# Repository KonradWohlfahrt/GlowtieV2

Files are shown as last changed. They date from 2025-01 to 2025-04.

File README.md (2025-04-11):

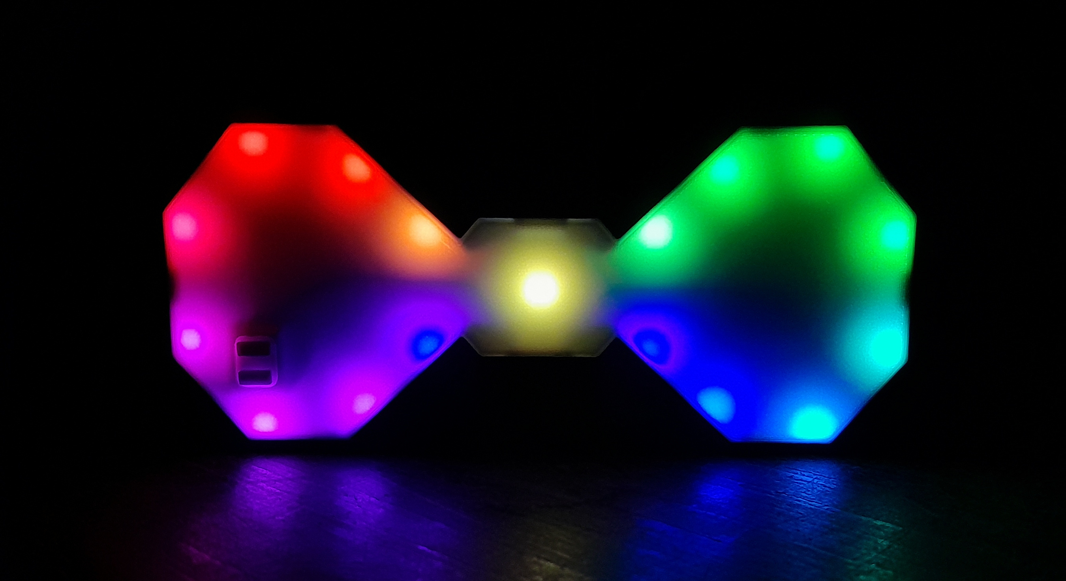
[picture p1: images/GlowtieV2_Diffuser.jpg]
Diffuser


# Glowtie V2
**Version 2 of my Glowtie adaptation: More glow for less (bow)tie!**
In this repo you will find the new project files for version 2 of the Glowtie!
It was originally designed by [Stephen Hawes](https://github.com/sphawes/glowtie).
Version 1 has served me well, but I still wanted to impove on the features and its look!
The old ESP8266 chip and Micro USB socket were exchanged with USB-C and the ESP32 C3.
Apart from two buttons and an I2S microphone, four more WS2812b leds were added to a slightly smaller pcb.
Finally, this project was made possible by [PCBWay](https://www.pcbway.com/)!
The awesome looking pcb for this project was fabricated by them.
Like last time I was satisfied with the quality and the black finish.
Creating circuit boards can be a tough task, but with such services it's made fast and simple!
If you have a project that involves pcb prototype, PCBWay offers services, such as pcb production, assembly as well as 3D printing and CNC machining for a small price!
Check out my full [guide](https://www.instructables.com/Glowtie-V2-a-Glowing-Bowtie/) at Instructables if you want to build one yourself too.

***
# Materials:
| Component | Amount | Silkscreen label |
|:---|:---:|---:|
| custom pcb | 1 | - |
| 3D printed case | 1 | - |
| 500 mAh LiPo battery (max size: 25mm x 35mm x 7mm) | 1 | - |
| M3x6 screw with nut | 2 | - |
| 100uF 1206 | 1 | C5 |
| 10uF 0805 | 3 | C2, C7, C8 |
| 1uF 0805 | 2 | C4, C6 |
| 100nF 0805 | 20 | C1, C3, C9-C27 |
| LED red 0805 | 1 | LED1 |
| LED green 0805 | 1 | LED2 |
| WS2812b 5050 | 17 | LED3-LED19 |
| 100r 0805 | 1 | R4 |
| 330r 0805 | 1 | R10 |
| 1k 0805 | 3 | R2, R3, R5 |
| 3k 0805 (charge programming resistor) | 1 | R1 |
| 10k 0805 | 5 | R6-R9, R12 |
| 33k 0805 | 1 | R11 |
| TP4056 | 1 | U4 |
| DW01A | 1 | U5 |
| FS8205A | 1 | Q1 |
| MCP1826S-3302 | 1 | U3 |
| ESP32-C3-WROOM-02 | 1 | U1 |
| SMD button 3 * 6 * 2.5 | 2 | SW2, SW3 |
| USB Type-C 4 pin | 1 | USB1 |
| SK12D07VG6 | 1 | SW1 |
| INMP441 I2S mic module | 1 | U2 |

***
# Schematic:
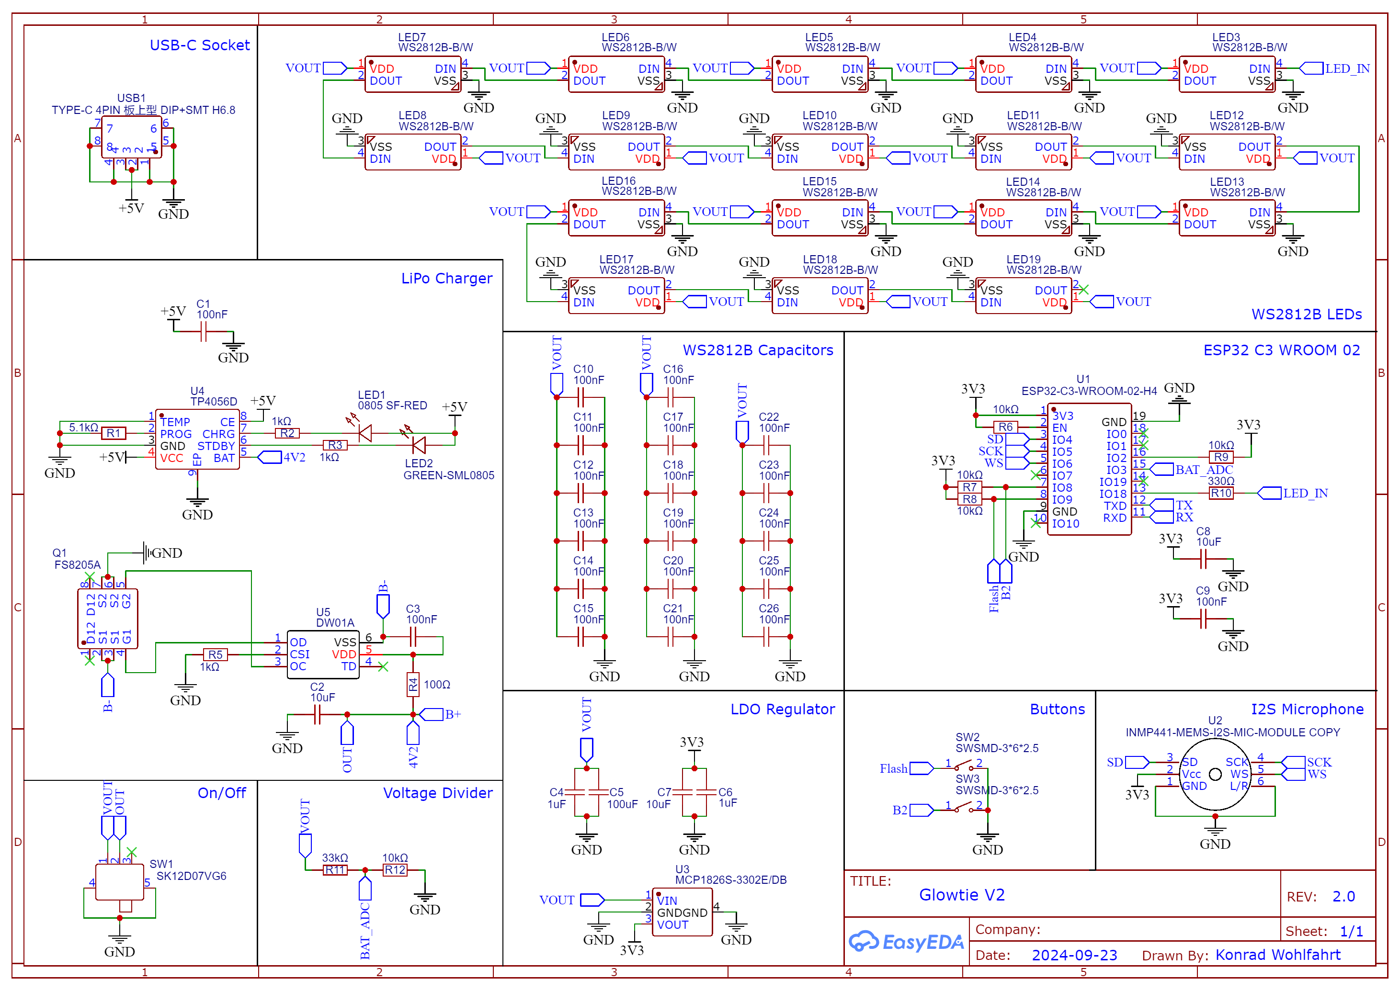
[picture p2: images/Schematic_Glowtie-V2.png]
Schematic

_Schematic for Version 2_
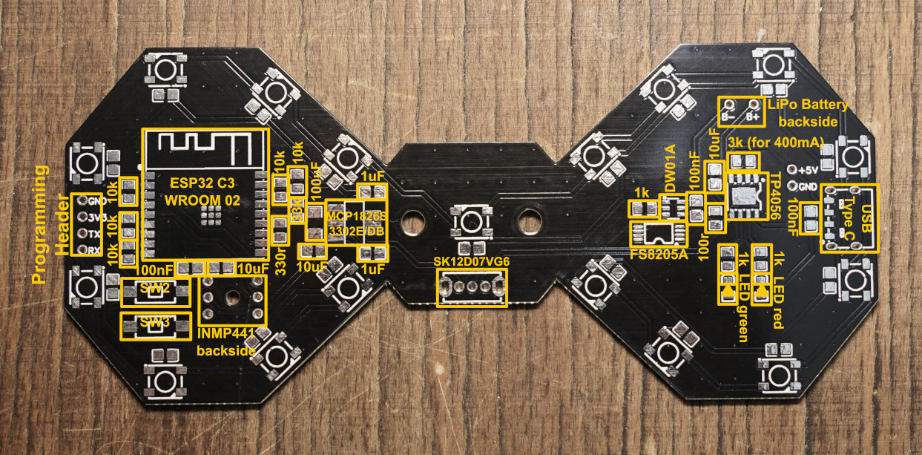
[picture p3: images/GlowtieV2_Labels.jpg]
SolderingLables

_Lables for soldering components_

**Note:**
During the development I have discovered an issue regarding the WiFi-Version:
I connected ADC Channel 2 (GPIO5) with the I2S microphone. During WiFi operation it won't be available!
Thus, you cannot use the music reactive effects while keeping WiFi enabled. 

***
# Programming
Programmed with the Arduino IDE and ESP32 board manager. 
Install the following libraries:

WiFi Version
- [WS2812FX](https://github.com/kitesurfer1404/WS2812FX)
- [ESPAsyncWebServer](https://github.com/me-no-dev/ESPAsyncWebServer)

BLE/Mic Version
- [WS2812FX](https://github.com/kitesurfer1404/WS2812FX)
- [ArduinoFFT](https://github.com/kosme/arduinoFFT)

**Uploading:**
Board: `ESP32C3 Dev Module`
Settings: default
Connections for FTDI programmer (3.3V logic level):
- Glowtie -> FTDI
- TX -> RX
- RX -> TX
- VCC -> VCC
- GND -> GND
Press and hold the upper button (Flash) when powering up the programmer until the sketch started uploading.
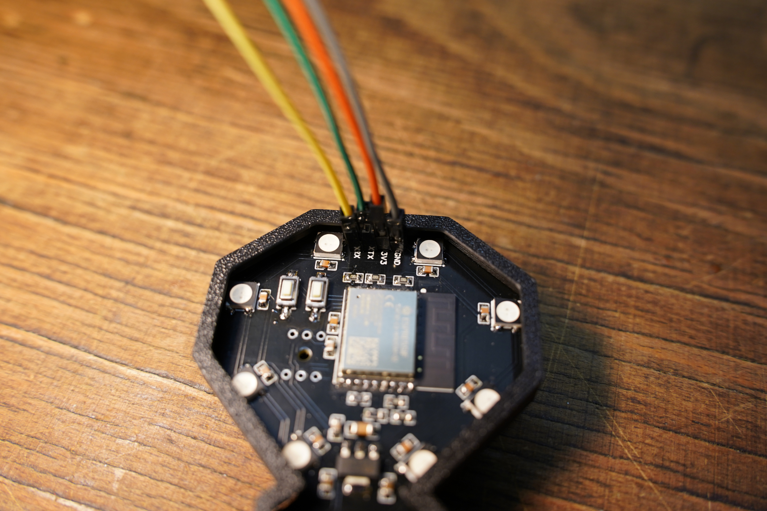
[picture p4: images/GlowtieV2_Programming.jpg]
Programming


***
# 3D Printing
Depending on your application you want to print `Glowtie` or `Glowtie Slot`, both upside down with support enabled. The `Bumper` is optional but will make it look better and offers protection. The `Diffuser` can only be placed on the bumper and will hide the pcb as well as diffuse the leds. This makes the Glowtie look more elegant! Keep in mind that if you want to access the buttons, print `Diffuser Cutout` and the corresponding button raiser.

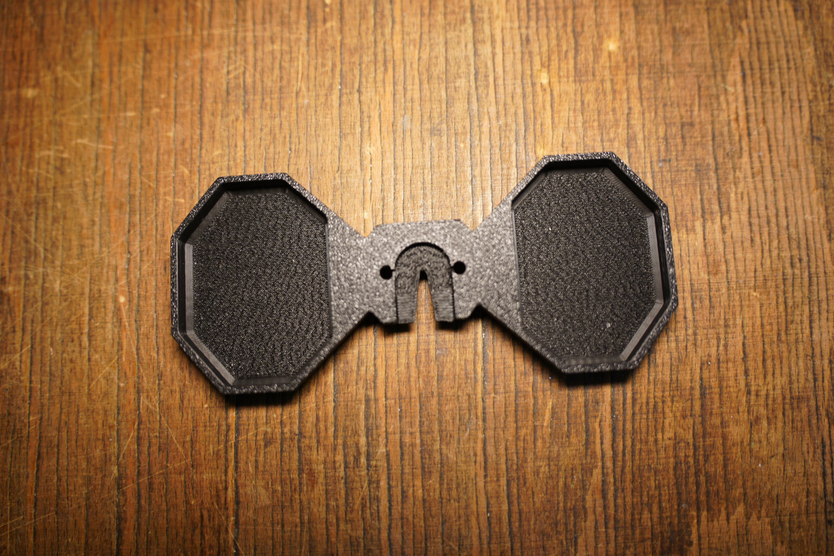
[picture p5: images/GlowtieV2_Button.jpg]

_case for button_
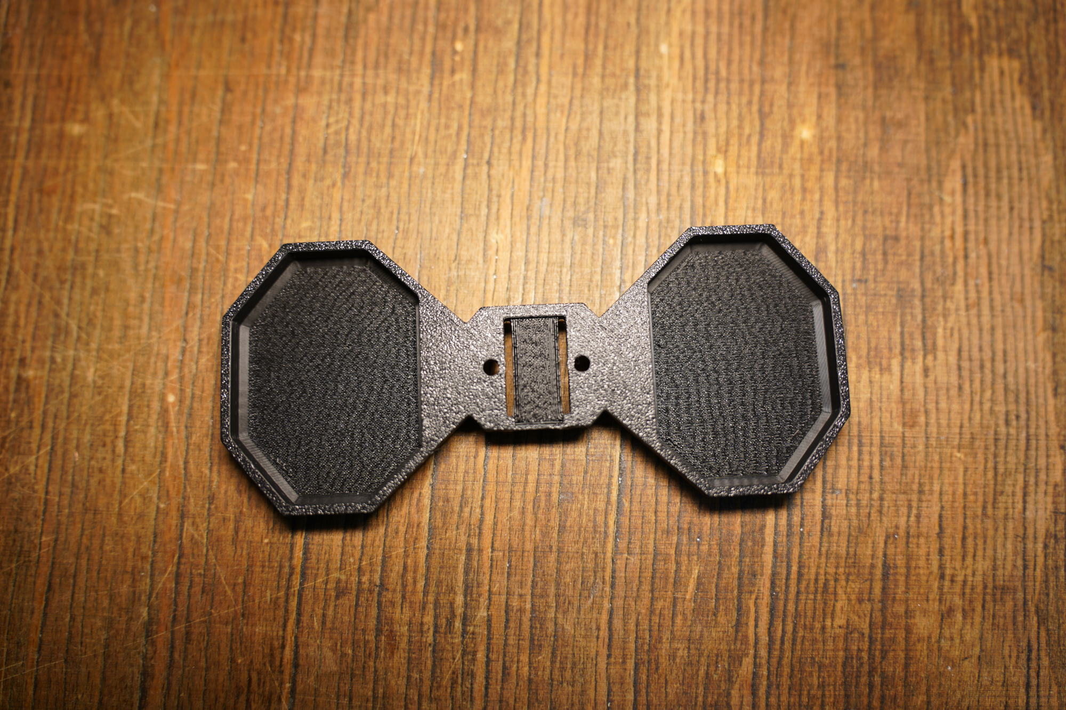
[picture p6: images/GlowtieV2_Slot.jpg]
RibbonCase

_case for ribbon_

***
# BLE Application
With Bluetooth Low Energy you need a dedicated application to change the characteristics.
I soon realized that learning a new framework takes a lot of time, so I opted for [MIT App Inventor](https://appinventor.mit.edu/).
Building your own app with this tool is easy and fast with the cost of less freedom when it comes to design.
I will come back and create a proper app with a framework like React Native or .Net Maui.
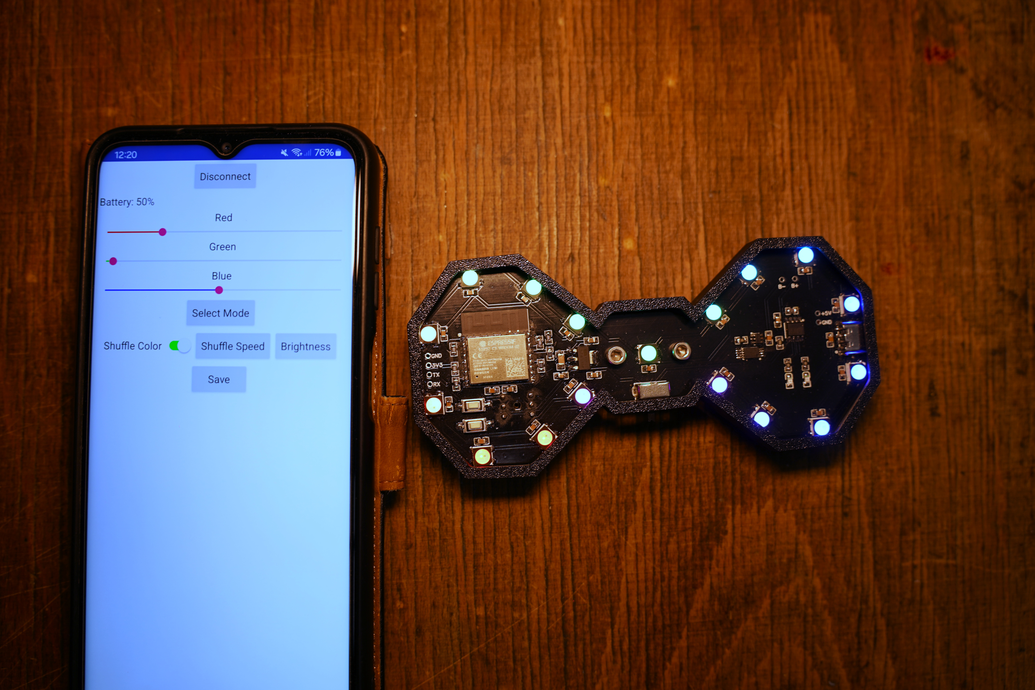
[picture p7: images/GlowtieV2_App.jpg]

_MIT App Inventor Application_

***
# Functions
The following buttons are used: upper button (Flash or B1) and lower button (B2).
Button functions:
- short press B1: show battery status
- short press B2: shuffle mode
- long press B1: save mode and color to eeprom
- long press B2: music mode
- double press B1: start BLE advertising (ble version) / swap to next effect (mic version)

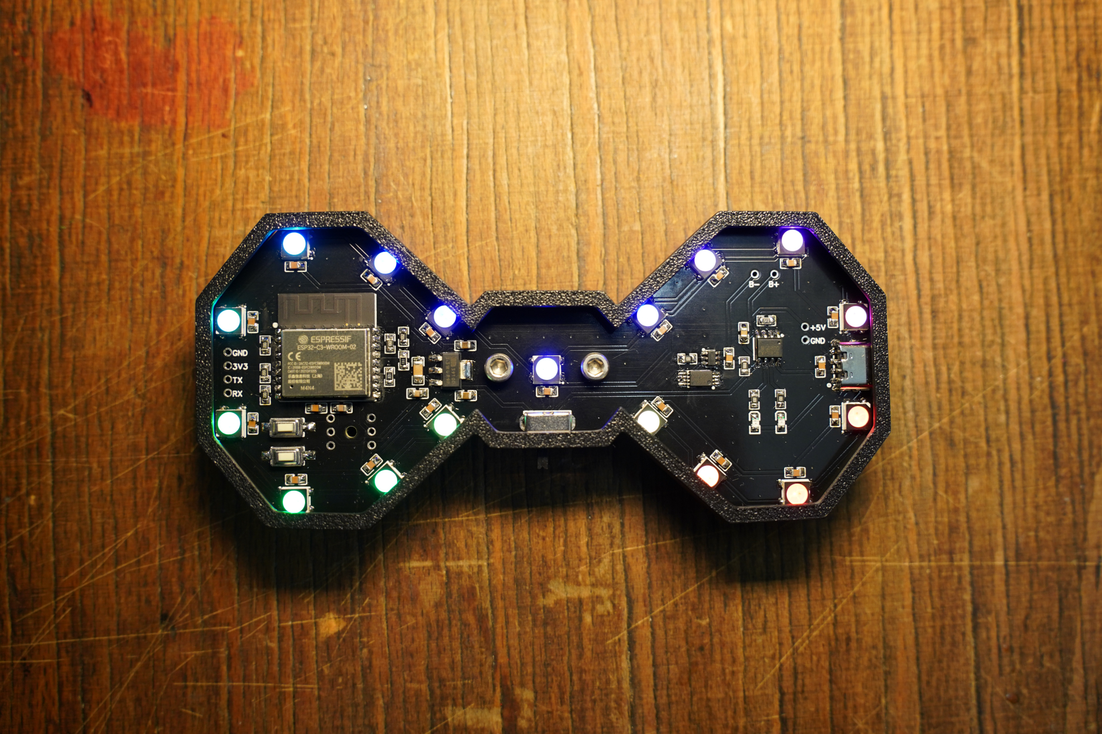
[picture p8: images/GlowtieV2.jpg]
Glowtie

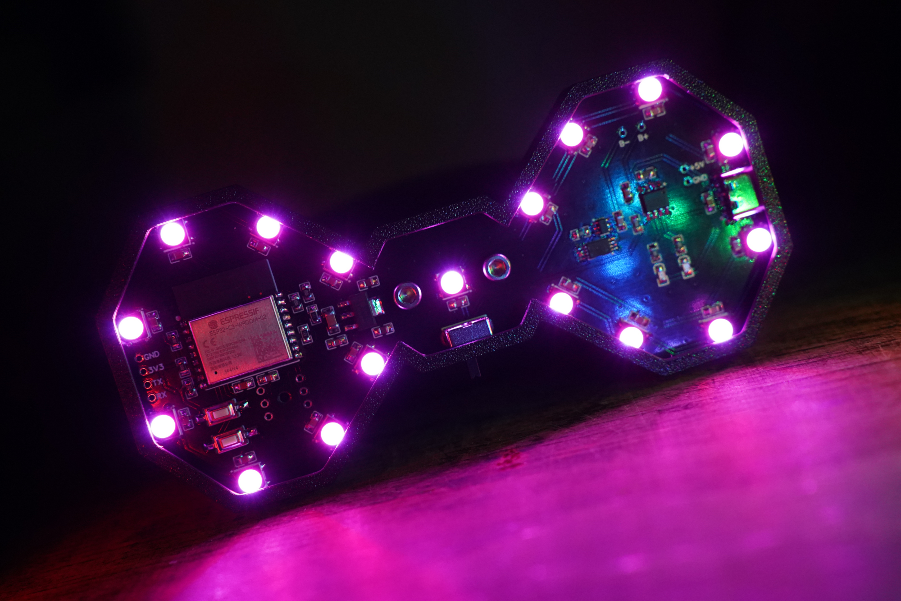
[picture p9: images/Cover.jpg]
Cover


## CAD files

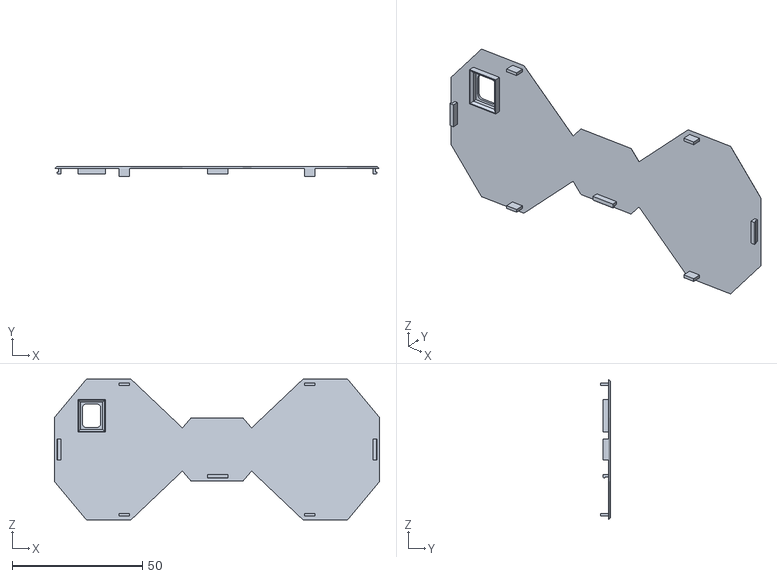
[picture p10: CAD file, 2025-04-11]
cad/Diffuser Cutout.stl
124.6 x 3.75 x 54.0

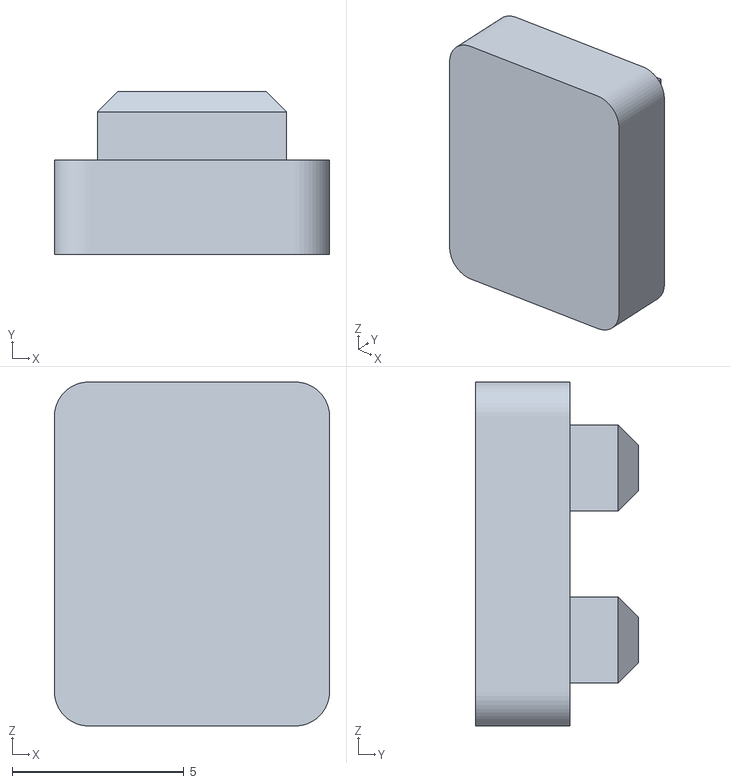
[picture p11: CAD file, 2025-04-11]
cad/Buttons.stl
8.00 x 4.75 x 10.0

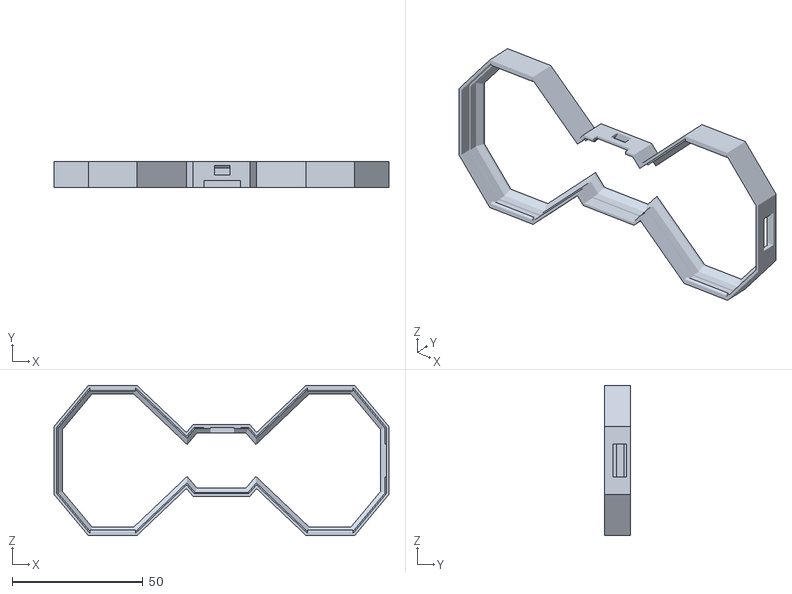
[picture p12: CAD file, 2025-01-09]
cad/Bumper.stl
128.0 x 9.75 x 57.4

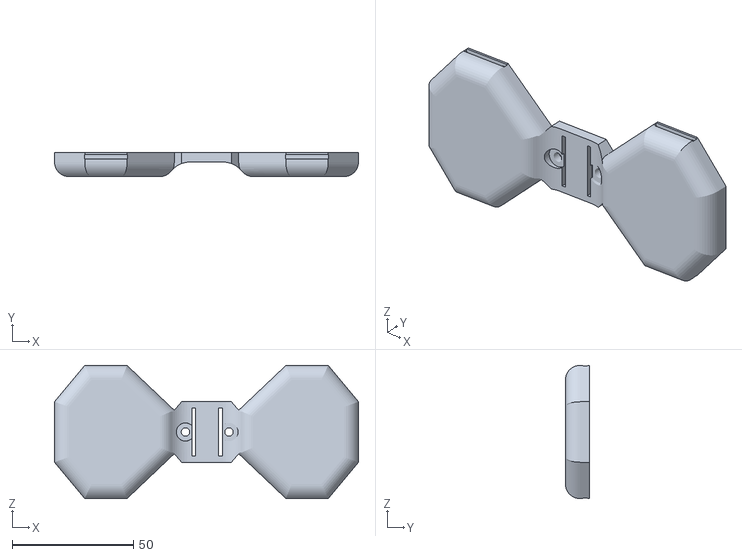
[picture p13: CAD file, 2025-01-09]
cad/Glowtie Slot.stl
125.6 x 10.0 x 55.0

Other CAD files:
cad/Diffuser.stl
cad/Glowtie.stl

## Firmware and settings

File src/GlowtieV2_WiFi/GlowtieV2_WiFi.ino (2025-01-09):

#include <WiFi.h>
#include <ESPAsyncWebServer.h>
#include <EEPROM.h>

#include "webserver.h"

#define EEPROMSIZE 7

// Battery
#define BATPIN 3
#define BATTERYCHECKINTERVAL 5000
#define LOWBATTERYVOLTS 3500
#define TURNOFFVOLTS 3400


// Buttons
#define B1 9
#define B2 8
#define LONGPRESSTIME 1000

const char *ssid = "GlowtieV2";
const char *password = "password";

const uint8_t _brightness[] = { 10, 20, 30, 40 };
const unsigned long _shuffleTimeMin[] = { 120000, 45000, 30000, 10000 };
const unsigned long _shuffleTimeMax[] = { 360000, 90000, 60000, 20000 };


AsyncWebServer server(80);

/* --- UTILITY START --- */

bool button1() { return digitalRead(B1) == 0; }
bool button2() { return digitalRead(B2) == 0; }
bool anyButton() { return button1() || button2(); }
bool bothButtons() { return button1() && button2(); }

uint16_t getBatteryVoltage() 
{ 
  double avg = 0;
  for (uint8_t i = 0; i < 6; i++)
  {
    avg += analogReadMilliVolts(BATPIN);
    delay(2);
  }
  avg /= 6;
  return (uint16_t)(4.3 * avg);
}
double getBatteryPercent() { return constrain(((getBatteryVoltage() - LOWBATTERYVOLTS) / (4200.0 - LOWBATTERYVOLTS) * 100), 0, 100); }
bool isTimestamp(unsigned long& timestamp, unsigned long interval) 
{
  if (millis() - timestamp >= interval)
  {
    timestamp = millis();
    return true;
  }
  return false;
}

/* --- UTILITY END --- */


/* --- FX START --- */
uint8_t _red = 255;
uint8_t _green = 255;
uint8_t _blue = 255;
uint32_t _currentColor = 0xFFFFFF;

int _effectCounter;

#include "Effect.h"

#include "Static.h"

#include "Burst.h"
#include "Pulse.h"
#include "Bar.h"
#include "Chaser.h"

#include "Infinity.h"
#include "Circles.h"
#include "Symmetry.h"

#include "Rainbow.h"
#include "LibraryFX.h"

const uint8_t _effectsCount = 25;
GlowtieEffect * _effects[] = { new Solid(), new Half(), new RainbowSolid(),
                              new Burst(), new Pulse(), new Bar(), new Scanner(), new Filler(), new Chaser(),
                              new Infinity(), new InfinityFill(),
                              new Circles(), new CirclesFill(),
                              new Symmetry(), new SymmetryFill(),
                              new Rainbow(), new RainbowFill(),
                              new Breathe(), new RunningLights(), new Fireworks(), new FireworksRandom(),
                              new TwinkleFade(), new TwinkleFOX(), new FireFlicker(), new FlashSparkle() };

uint8_t _currentEffectIndex = 0;
uint8_t _currentBrightness;
int _effectSpeed;
bool _effectStatic;
unsigned long __lastFXLoop;
/* --- FX END --- */


// BATTERY
unsigned long __lastBatteryCheck;

// shuffle mode
bool _changeColor;
bool _shuffleActive = false;
uint8_t _shuffleSpeedIndex;
unsigned long _shuffleTime;
unsigned long __lastShuffle;


void setup() 
{
  pinMode(B1, INPUT);
  pinMode(B2, INPUT);
  pinMode(BATPIN, INPUT);
  analogSetAttenuation(ADC_2_5db); // adc range: 0mV - 1050mV
  
  pixels.init();
  pixels.setBrightness(15);
  pixels.setPixelColor(8, RED);
  pixels.show();

  if (!EEPROM.begin(EEPROMSIZE))
  {
    flashAnim(RED, 5);
    lowBattery();
    delay(5000);
    ESP.restart();
  }
  delay(250);
  
  _currentEffectIndex = constrain(EEPROM.read(0), 0, _effectsCount - 1);

  _red = EEPROM.read(1);
  _green = EEPROM.read(2);
  _blue = EEPROM.read(3);
  _currentColor = pixels.Color(_red, _green, _blue);
  pixels.setColor(_currentColor);

  _currentBrightness = constrain(EEPROM.read(4), 0, 3);
  pixels.setBrightness(_brightness[_currentBrightness]);

  _shuffleSpeedIndex = constrain(EEPROM.read(5), 0, 3);
  _changeColor = EEPROM.read(6) == 0;
  

  WiFi.mode(WIFI_AP);
  if (WiFi.softAP(ssid, password, 1, 0, 1))
    scrollAnim(GREEN);
  else
    flashAnim(RED, 5);

  // initialize the server
  server.on("/", handleRoot);
  server.on("/red", HTTP_GET, handleGetRed);
  server.on("/green", HTTP_GET, handleGetGreen);
  server.on("/blue", HTTP_GET, handleGetBlue);
  server.on("/mode", HTTP_GET, handleGetMode);
  server.on("/vcc", HTTP_GET, handleGetVCC);
  server.on("/color", HTTP_GET, handleGetRandomColor);
  server.on("/speed", HTTP_GET, handleGetSpeed);
  server.on("/brightness", HTTP_GET, handleGetBrightness);
  server.begin();

  startEffect();
}
void loop() 
{
  if (isTimestamp(__lastBatteryCheck, BATTERYCHECKINTERVAL)) 
  {
    if (getBatteryVoltage() < LOWBATTERYVOLTS)
    {
      WiFi.mode(WIFI_OFF);
      lowBattery();
      while (true)
      {
        if (getBatteryVoltage() < TURNOFFVOLTS)
        {
          pixels.setPixelColor(8, 20, 0, 0, 0);
          pixels.show();
          esp_deep_sleep_start();
        }
        delay(100);
      }
    }
  }

  handleButtons();
  
  handleEffects();
}

void handleButtons()
{
  // button 1: show battery(short) + save to eeprom(long)
  if (button1())
  {
    bool s = true;
    unsigned long start = millis();
    while (button1())
    {
      handleEffects();
      if (s && millis() - start >= LONGPRESSTIME)
      {
        s = false;
        flashAnim(GREEN, 4);
        EEPROM.write(0, _currentEffectIndex);
        EEPROM.write(1, _red);
        EEPROM.write(2, _green);
        EEPROM.write(3, _blue);
        EEPROM.commit();
        delay(250);
      }
      delay(5);
    }

    if (s)
      showBatteryPercent();
  }
  // button 2: shuffle mode(short)
  else if (button2())
  {
    while (button2())
    {
      handleEffects();
      delay(5);
    }

    _shuffleActive = !_shuffleActive;
    flashSingleAnim(_shuffleActive ? GREEN : RED, 8, 3);
    __lastShuffle = millis();
    _shuffleTime = random(_shuffleTimeMin[_shuffleSpeedIndex], _shuffleTimeMax[_shuffleSpeedIndex]);

    if (!_shuffleActive)
    {
      _currentEffectIndex = constrain(EEPROM.read(0), 0, _effectsCount - 1);
      _red = EEPROM.read(1);
      _green = EEPROM.read(2);
      _blue = EEPROM.read(3);
      updateColor();
    }

    startEffect();
  }
}

void handleEffects()
{
  if (!_effectStatic && isTimestamp(__lastFXLoop, _effectSpeed))
    _effects[_currentEffectIndex]->onUpdate(_effectCounter);

  if (_shuffleActive && isTimestamp(__lastShuffle, _shuffleTime)) 
  {
    if (_changeColor)
    {
      _currentColor = getRandomColor();
      _red = (uint8_t)(_currentColor >> 16);
      _green = (uint8_t)(_currentColor >> 8);
      _blue = (uint8_t)_currentColor; 
    }

    int m;
    do {
      m = random(0, _effectsCount);
    } while (m == _currentEffectIndex);
    _currentEffectIndex = m;
    _shuffleTime = random(_shuffleTimeMin[_shuffleSpeedIndex], _shuffleTimeMax[_shuffleSpeedIndex]);

    startEffect();
  }
}
void startEffect()
{
  pixels.clear();
  pixels.stop();
  pixels.setColor(_currentColor);

  _effectSpeed = _effects[_currentEffectIndex]->getSpeed();
  _effectStatic = _effects[_currentEffectIndex]->getIsStatic();
  _effects[_currentEffectIndex]->onStart(_effectCounter);
}
void updateColor()
{
  _currentColor = pixels.Color(_red, _green, _blue);
  if (_effectStatic)
    startEffect();
}


void handleGetRed(AsyncWebServerRequest* request) { request->send(200, "text/plane", String(_red)); }
void handleGetGreen(AsyncWebServerRequest* request) { request->send(200, "text/plane", String(_green)); }
void handleGetBlue(AsyncWebServerRequest* request) { request->send(200, "text/plane", String(_blue)); }
void handleGetMode(AsyncWebServerRequest* request) { request->send(200, "text/plane", String(_currentEffectIndex)); }
void handleGetVCC(AsyncWebServerRequest* request) { request->send(200, "text/plane", String((int)getBatteryPercent()) + "% (" + String(getBatteryVoltage()) + "mV)"); }
void handleGetRandomColor(AsyncWebServerRequest* request) { request->send(200, "text/plane", (_changeColor ? "1" : "0")); }
void handleGetSpeed(AsyncWebServerRequest* request) { request->send(200, "text/plane", String(_shuffleSpeedIndex)); }
void handleGetBrightness(AsyncWebServerRequest* request) { request->send(200, "text/plane", String(_currentBrightness)); }
void handleRoot(AsyncWebServerRequest* request)
{
  if (request->args() > 0) 
  {
    if (request->hasArg("red"))
    {
      _red = (uint8_t)request->arg("red").toInt();
      _green = (uint8_t)request->arg("green").toInt();
      _blue = (uint8_t)request->arg("blue").toInt();
      updateColor();

      _currentEffectIndex = constrain((uint8_t)request->arg("mode").toInt(), 0, _effectsCount - 1);

      __lastShuffle = millis();

      request->send(200, "text/html", index_html);

      startEffect();
    }
    else
    {
      _currentBrightness = constrain(request->arg("brightness").toInt(), 0, 3);
      EEPROM.write(4, _currentBrightness);
      _shuffleSpeedIndex = constrain(request->arg("speed").toInt(), 0, 3);
      EEPROM.write(5, _shuffleSpeedIndex);
      _changeColor = request->hasArg("randomcolor");
      EEPROM.write(6, _changeColor ? 0 : 255);
      
      

      if (pixels.getBrightness() != _brightness[_currentBrightness])
        pixels.setBrightness(_brightness[_currentBrightness]);

      request->send(200, "text/html", index_html);
  
      flashAnim(GREEN, 4);
      EEPROM.commit();
      delay(250);
      
      startEffect();
    }
  }
  else
    request->send(200, "text/html", index_html);
}

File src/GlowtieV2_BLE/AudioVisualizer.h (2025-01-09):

#ifndef AUDIOVISUALIZER_h
#define AUDIOVISUALIZER_h

const int xresGraph = 8;
const int yresGraph = 9;

class FrequencyGraph : public GlowtieEffect
{
  public:
    FrequencyGraph() : GlowtieEffect(50, false, true) { }

    void onStart(int& i) 
    { 
      step = (SAMPLE_BUFFER_SIZE / 2) / xresGraph;
      _halfCol = pixels.Color(_red / 2, _green / 2, _blue / 2);
      i = 0;
    }
    void onUpdate(int& i) 
    {
      performFFT();

      int c = 0;
      for (int i = 0; i < (SAMPLE_BUFFER_SIZE / 2); i += step)
      {
        int v = 0;
        for (int j = 0; j < step; j++)
            v += vReal[i + j];
        sBar[c] = constrain((v / step), 0, 255);
        c++;
      }

      pixels.clear();
      for (int i = 0; i < xresGraph; i++)
      {
        sBar[i] = map(sBar[i], 0, 255, 0, yresGraph);
        
        peaks[i] = peaks[i] - 1;
        if (sBar[i] > peaks[i])
          peaks[i] = sBar[i];
        peaks[i] = sBar[i];

        setFreqBar(i, peaks[i]);
      }
      if (i > 4)
      {
        pixels.setPixelColor(8, 0);
        i = 0;
      }
      pixels.show();

      i++;
    }
    void onSound(int& i) { pixels.setPixelColor(8, _currentColor); pixels.show(); i = 0; }

    private:
      const uint8_t bars[8][2] = {
        { 3, 4 },
        { 2, 5 },
        { 1, 6 },
        { 0, 7 },
        { 16, 9 },
        { 15, 10 },
        { 14, 11 },
        { 13, 12 }
      };

      int step = 0;
      uint8_t sBar[xresGraph];
      uint8_t peaks[xresGraph];
      uint32_t _halfCol;

      void setFreqBar(int i, int y)
      {
        if (y <= 1)
          return;

        if (y <= 3) 
        {
          pixels.setPixelColor(bars[i][0], _halfCol);
        }
        else if (y <= 5)
        {
          pixels.setPixelColor(bars[i][0], _currentColor);
        }
        else if (y <= 7)
        {
          pixels.setPixelColor(bars[i][0], _currentColor);
          pixels.setPixelColor(bars[i][1], _halfCol);
        }
        else
        {
          pixels.setPixelColor(bars[i][0], _currentColor);
          pixels.setPixelColor(bars[i][1], _currentColor);
        }
      }
};

const int xresDots = 17;
const int yresDots = 8;

class FrequencyDots : public GlowtieEffect
{
  public:
    FrequencyDots() : GlowtieEffect(50, false, true) { }

    void onStart(int& i) 
    { 
      step = (SAMPLE_BUFFER_SIZE / 2) / xresDots;
      _halfCol = pixels.Color(_red / 2, _green / 2, _blue / 2);
      i = 0;
    }
    void onUpdate(int& i) 
    {
      performFFT();

      int c = 0;
      for (int i = 0; i < (SAMPLE_BUFFER_SIZE / 2); i += step)
      {
        int v = 0;
        for (int j = 0; j < step; j++)
            v += vReal[i + j];
        sBar[c] = constrain((v / step), 0, 255);
        c++;
      }

      pixels.clear();
      for (int i = 0; i < xresDots; i++)
      {
        sBar[i] = map(sBar[i], 0, 255, 0, yresDots);
        
        peaks[i] = peaks[i] - 1;
        if (sBar[i] > peaks[i])
          peaks[i] = sBar[i];
        peaks[i] = sBar[i];

        if (peaks[i] <= 2)
          pixels.setPixelColor(i, 0);
        else if (peaks[i] <= 5)
          pixels.setPixelColor(i, _halfCol);
        else
          pixels.setPixelColor(i, _currentColor);
      }
      
      pixels.show();
    }
    void onSound(int& i) {  }

    private:
      int step = 0;
      uint8_t sBar[xresDots];
      uint8_t peaks[xresDots];
      uint32_t _halfCol;
};

class VolumeLevel : public GlowtieEffect
{
  public:
    VolumeLevel() : GlowtieEffect(50, false, true) { }

    void onStart(int& i) { }
    void onUpdate(int& i) 
    {
      int height = constrain(getVolumeLevel(LED_COUNT + 1), 0, LED_COUNT + 1);
    
      peak -= 2;
      if (peak < 0)
        peak = 0;
      if (height > peak)
        peak = height;

      for (int i = 0; i < LED_COUNT; i++) {
        if(i >= peak)
          pixels.setPixelColor(i, 0);
        else
          pixels.setPixelColor(i, _currentColor);
      }
      pixels.show();
    }
    void onSound(int& i) { }

    private:
      int peak = 0;
};

#endif
